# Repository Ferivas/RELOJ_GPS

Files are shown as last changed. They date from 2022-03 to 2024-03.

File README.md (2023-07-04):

# RELOJ_GPS
Reloj GPS basado en matrices 8x8 y drivers A6282.
Se tiene un arreglo de 5 matrices 8x8 manejadas cada una por un driver A6282.
La resolución del display resultante es de 8x40 (8 filas por 40 columnnas). 
Los datos del display se guardan en un arreglo Buffram de 40 bytes

## MICROPYTHON DRIVER
Con Micropython se puede implementar un driver manejando los datos con una instancia del puerto SPI (la línea MOSI no se utiliza).
En este escenario se encontro que para manejar 4 matrices se necesitan 870us para actualizar los datos. Las interrupciones del timer se generan cada 2ms por lo que para un barrido de 8 columnas se tiene una frecuencia de refresco de f=1/(2*8ms)=62.5Hz. Con el osciloscopio se determina que las columas están encendidas 1.4ms, por lo que se tiene un tiempo de (1400-870)/1400=38% del tiempo útil con los datos. En la práctica el brillo es aceptable y no hay efecto de fantasma por la conmutación.
## CONEXION MATRIZ 16X16
Las matrices se arreglan en un formato de 16x16 como se inidica en la figura siguiente:

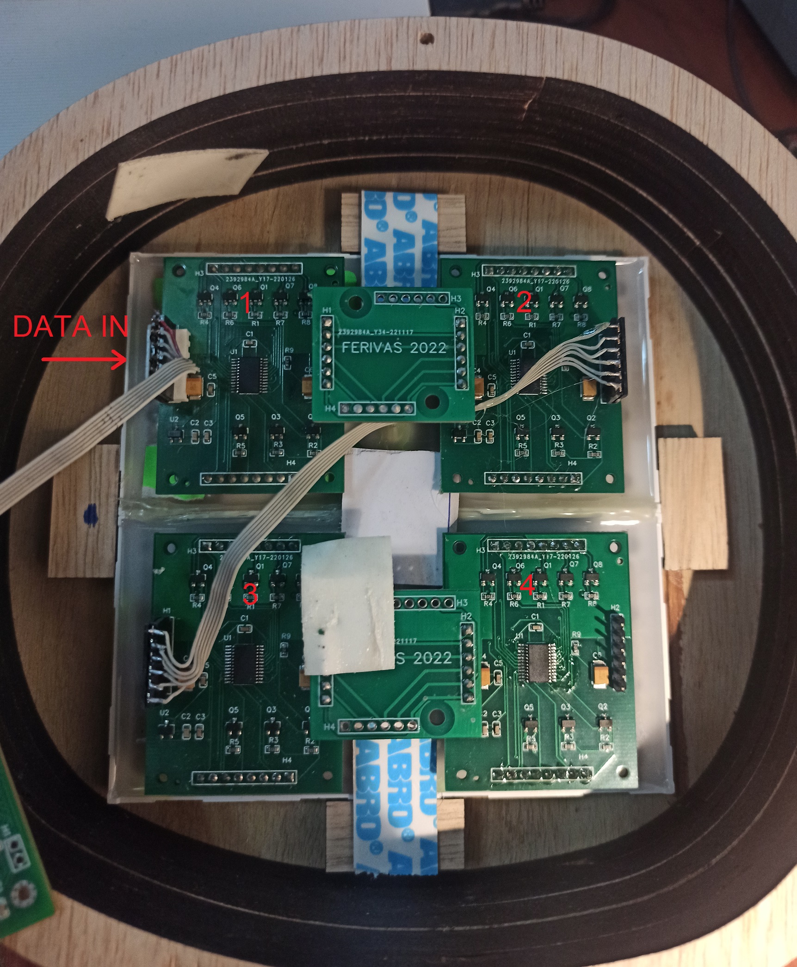
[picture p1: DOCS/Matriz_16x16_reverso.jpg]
Conexion Reverso


Con esta conexión la posición de las columnas para el arreglo bufferram en el programa de Micropython queda como se indica a continuación:

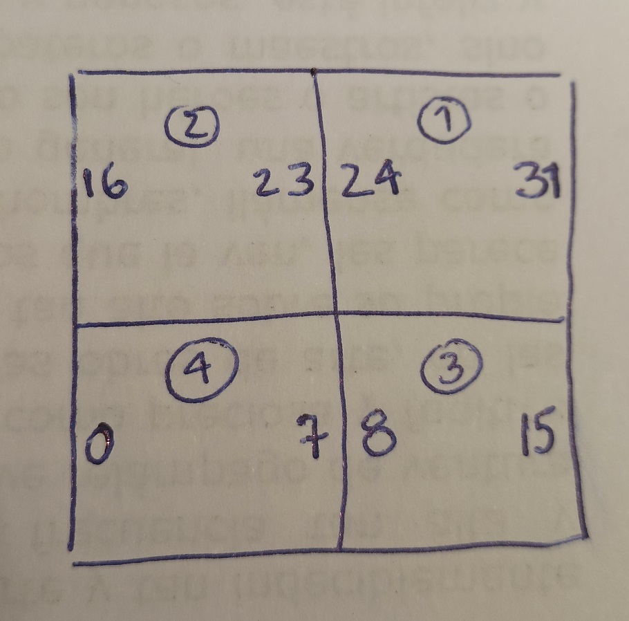
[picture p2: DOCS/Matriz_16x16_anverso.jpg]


En el programa de micropython las posiciones de los dígitos se asignan en una lista 

tblposdig=[10,2,23,16,25,31]

en donde el elemento 0 corresponde a la posición de las unidades de minuto, el elemento 1 a las decenas de minuto, el elemento 2 a las unidades de hora y el elemento 3 a las decenas de hora. 

El reloj por el frente

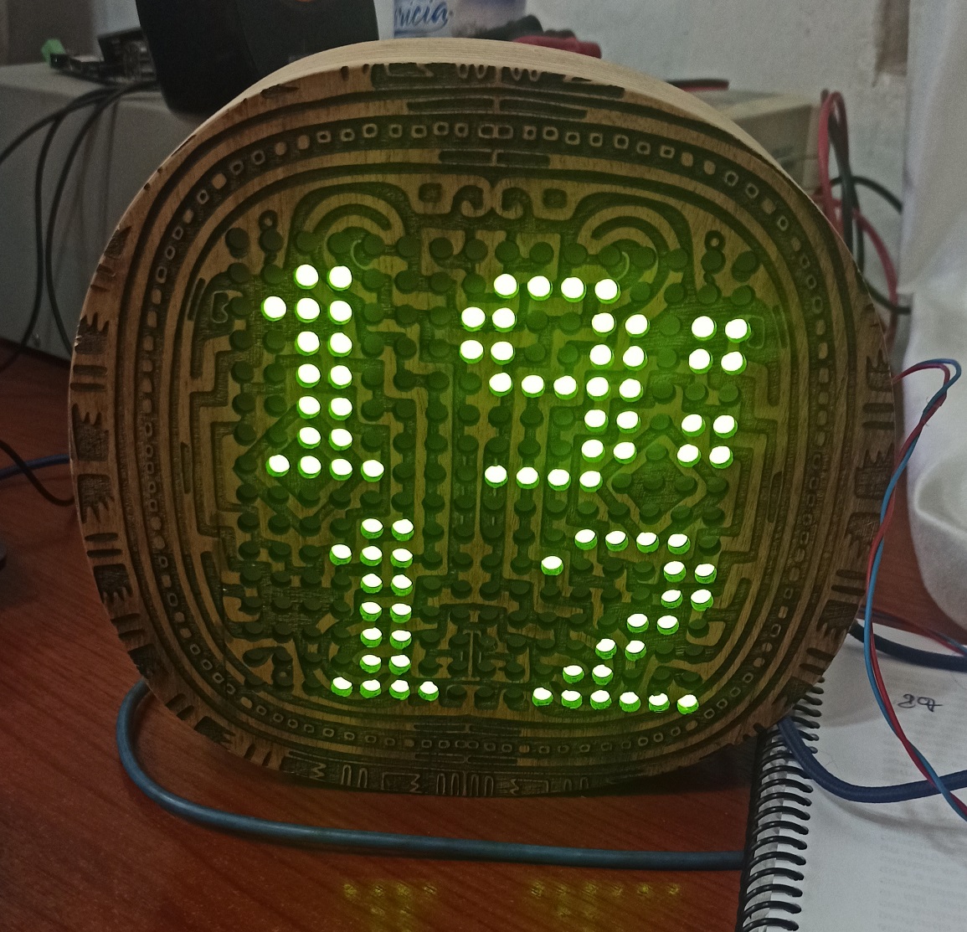
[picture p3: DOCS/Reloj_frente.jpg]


## BUGS RELOJ BASADO EN ESP32 CON TARJETA JLCPCB
### BUGS HARDWARE
Se debe desconectar la línea PWM que une a los dos drivers. Esta línea se debe manejar por separado. Cuando estaban unidos solo se enciende el segundo driver.
El corte esta indicado en la figura siguiente:

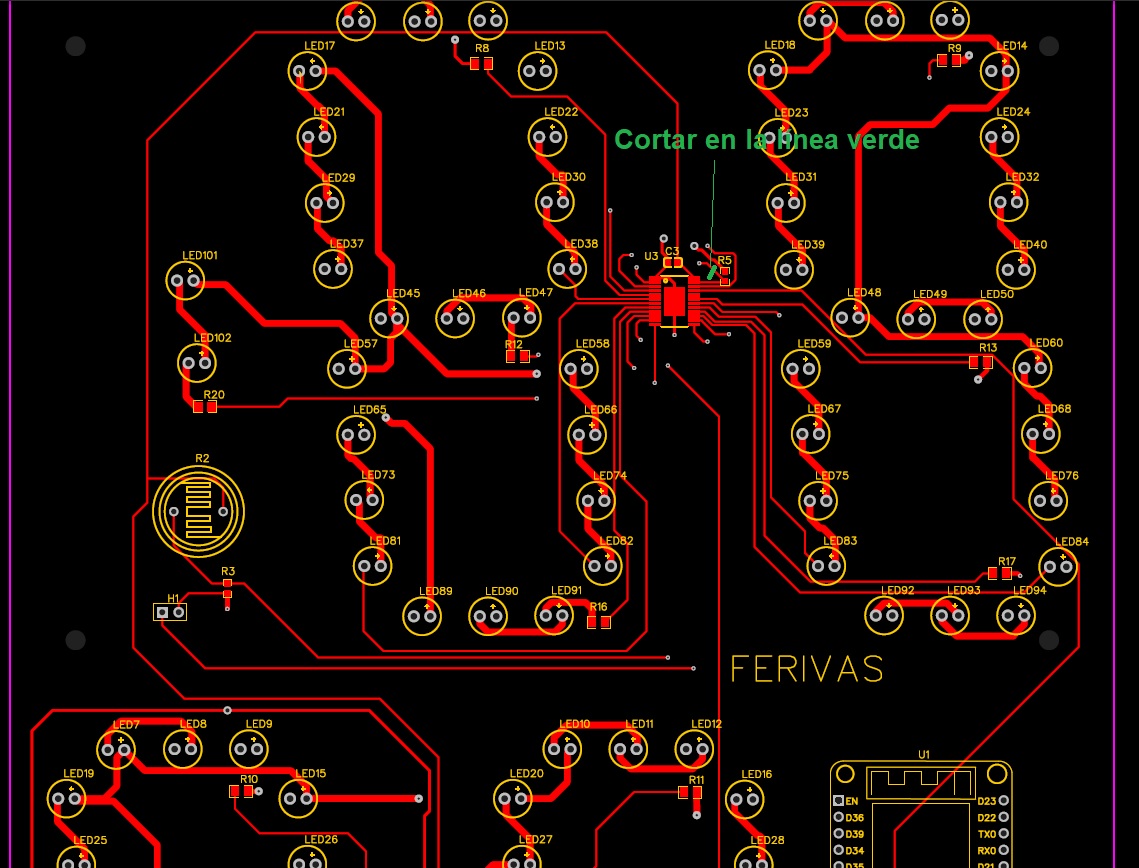
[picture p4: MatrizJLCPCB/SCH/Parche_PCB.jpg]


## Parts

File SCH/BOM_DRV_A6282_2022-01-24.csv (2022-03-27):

ID | Name | Designator | Footprint | Quantity | Manufacturer Part | Manufacturer | Supplier | Supplier Part | Price | JLCPCB Part Class
1 | 100nF | C1,C3,C5 | C0603 | 3 | CC0603KRX7R9BB104 | YAGEO | LCSC | C14663 | 0.003 | Basic Part
2 | 10uF | C2 | C0603 | 1 | CL10A106MA8NRNC | SAMSUNG | LCSC | C96446
3 | 100uF | C4,C6 | CAP-SMD_L3.5-W2.8 | 2 | TAJB107K006RNJ | AVX | LCSC | C16133 | 0.194 | Basic Part
4 | A2541WV-6P | H1,H2 | HDR-TH_6P-P2.54-V-M-1 | 2 | A2541WV-6P | Changjiang Connectors | LCSC | C225481 | 0.119 | Extended Part
5 | AO3401A | Q1,Q2,Q3,Q4,Q5,Q6,Q7,Q8 | SOT-23_L2.9-W1.3-P1.90-LS2.4-BR | 8 | AO3401A | AOS | LCSC | C15127 | 0.149 | Basic Part
6 | 47K | R1,R2,R3,R4,R5,R6,R7,R8 | R0603 | 8 | 0603WAF4702T5E | UniOhm | LCSC | C25819 | 0.001 | Basic Part
7 | 470 | R9 | R0603 | 1 | 0603WAF4700T5E | UniOhm | LCSC | C23179 | 0.001 | Basic Part
8 | XC6206P332MR | U2 | SOT-23-3_L2.9-W1.6-P1.90-LS2.8-BR | 1 | XC6206P332MR | TOREX | LCSC | C5446 | 0.131 | Basic Part

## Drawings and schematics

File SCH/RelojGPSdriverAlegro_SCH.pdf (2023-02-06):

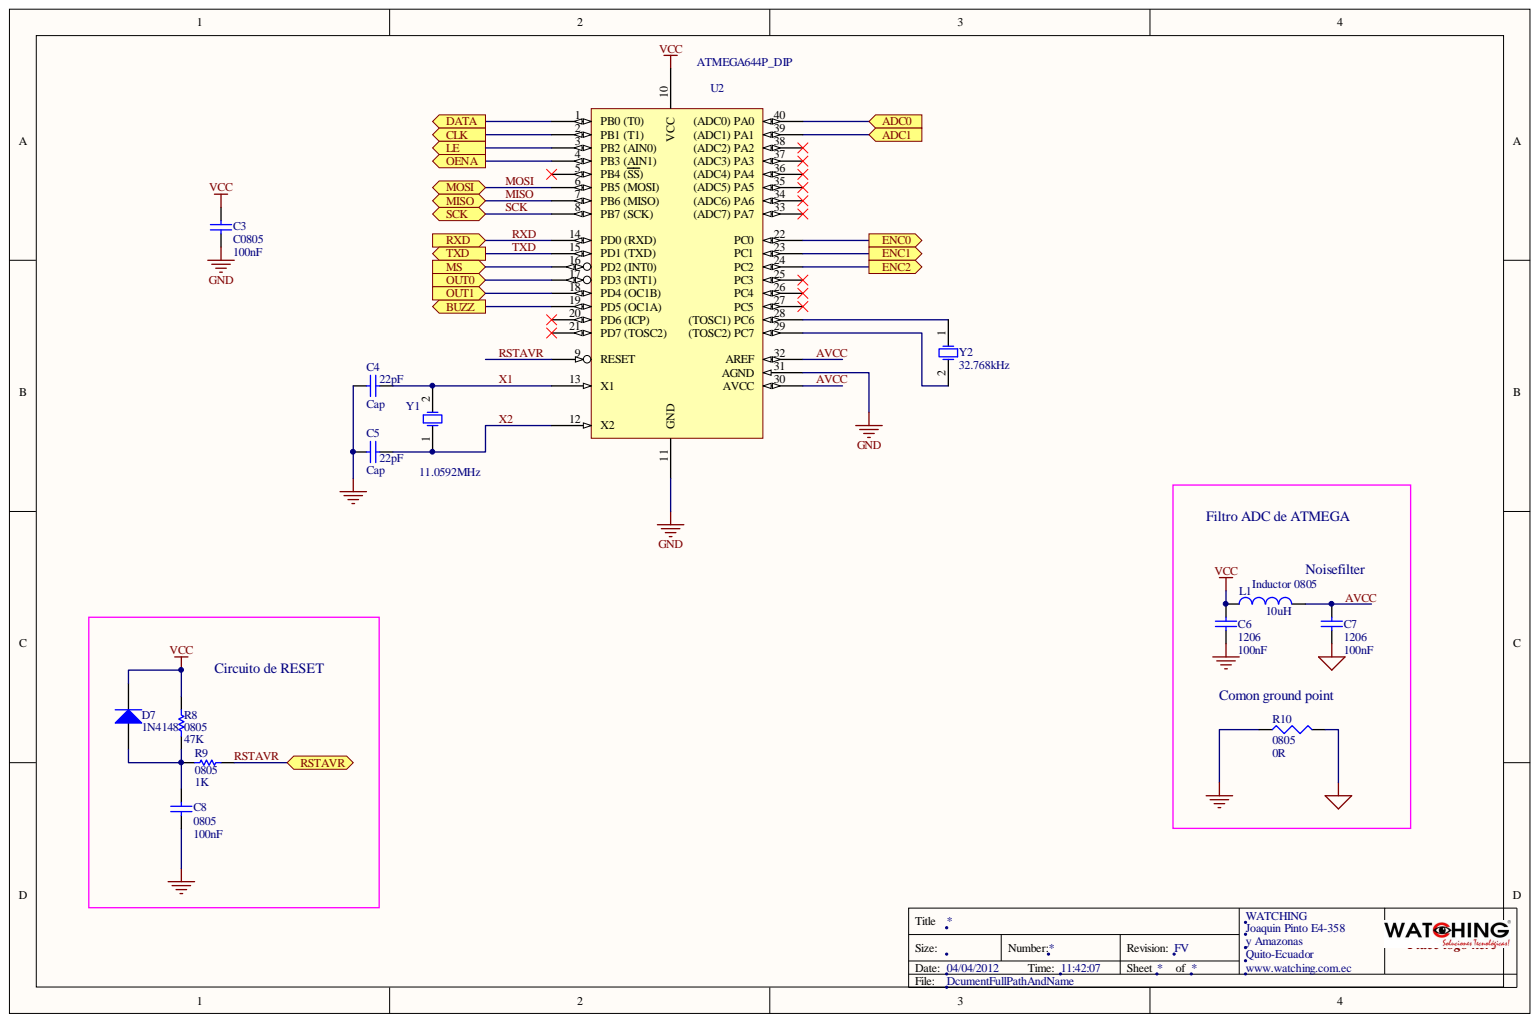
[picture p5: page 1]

Filtro ADC de ATMEGA

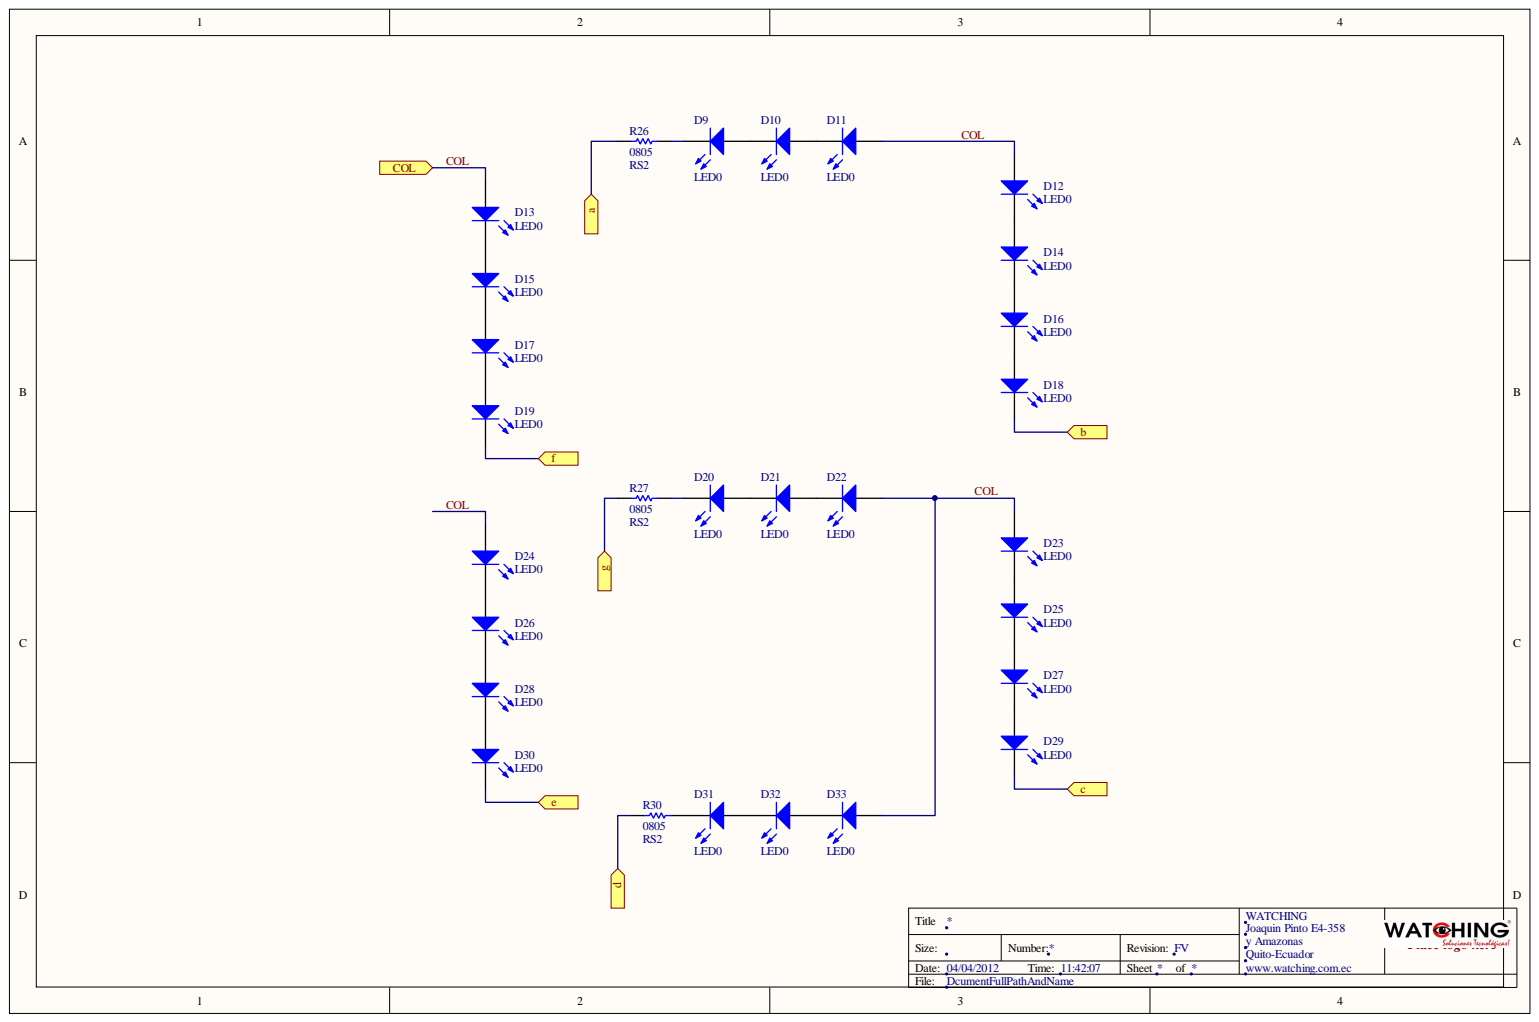
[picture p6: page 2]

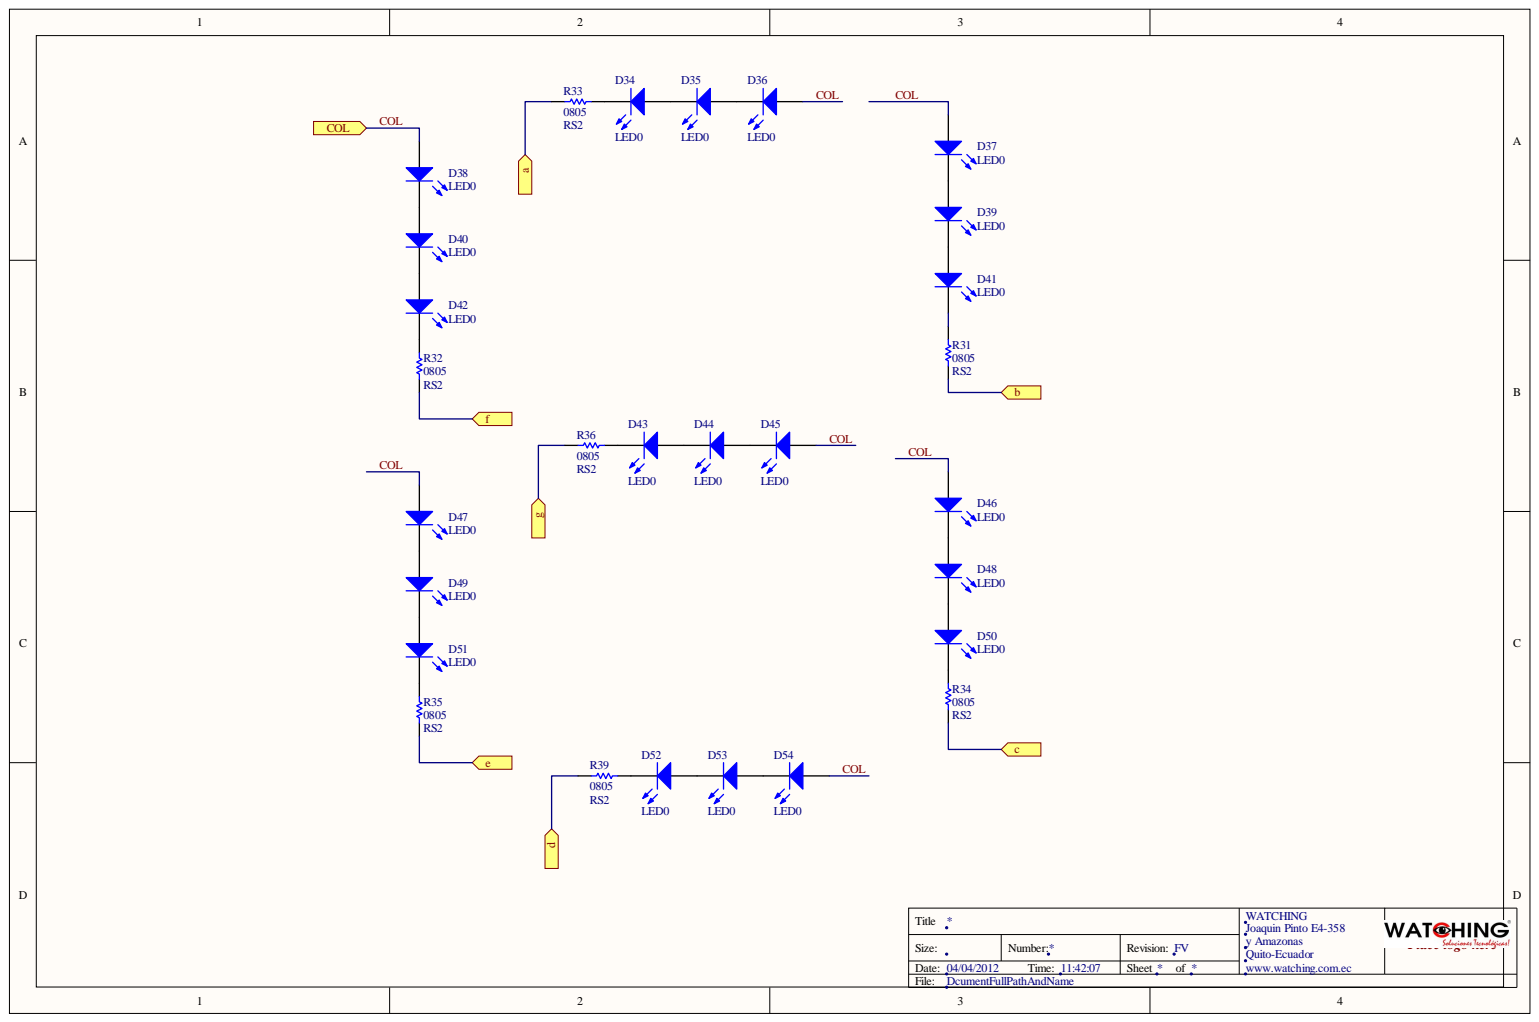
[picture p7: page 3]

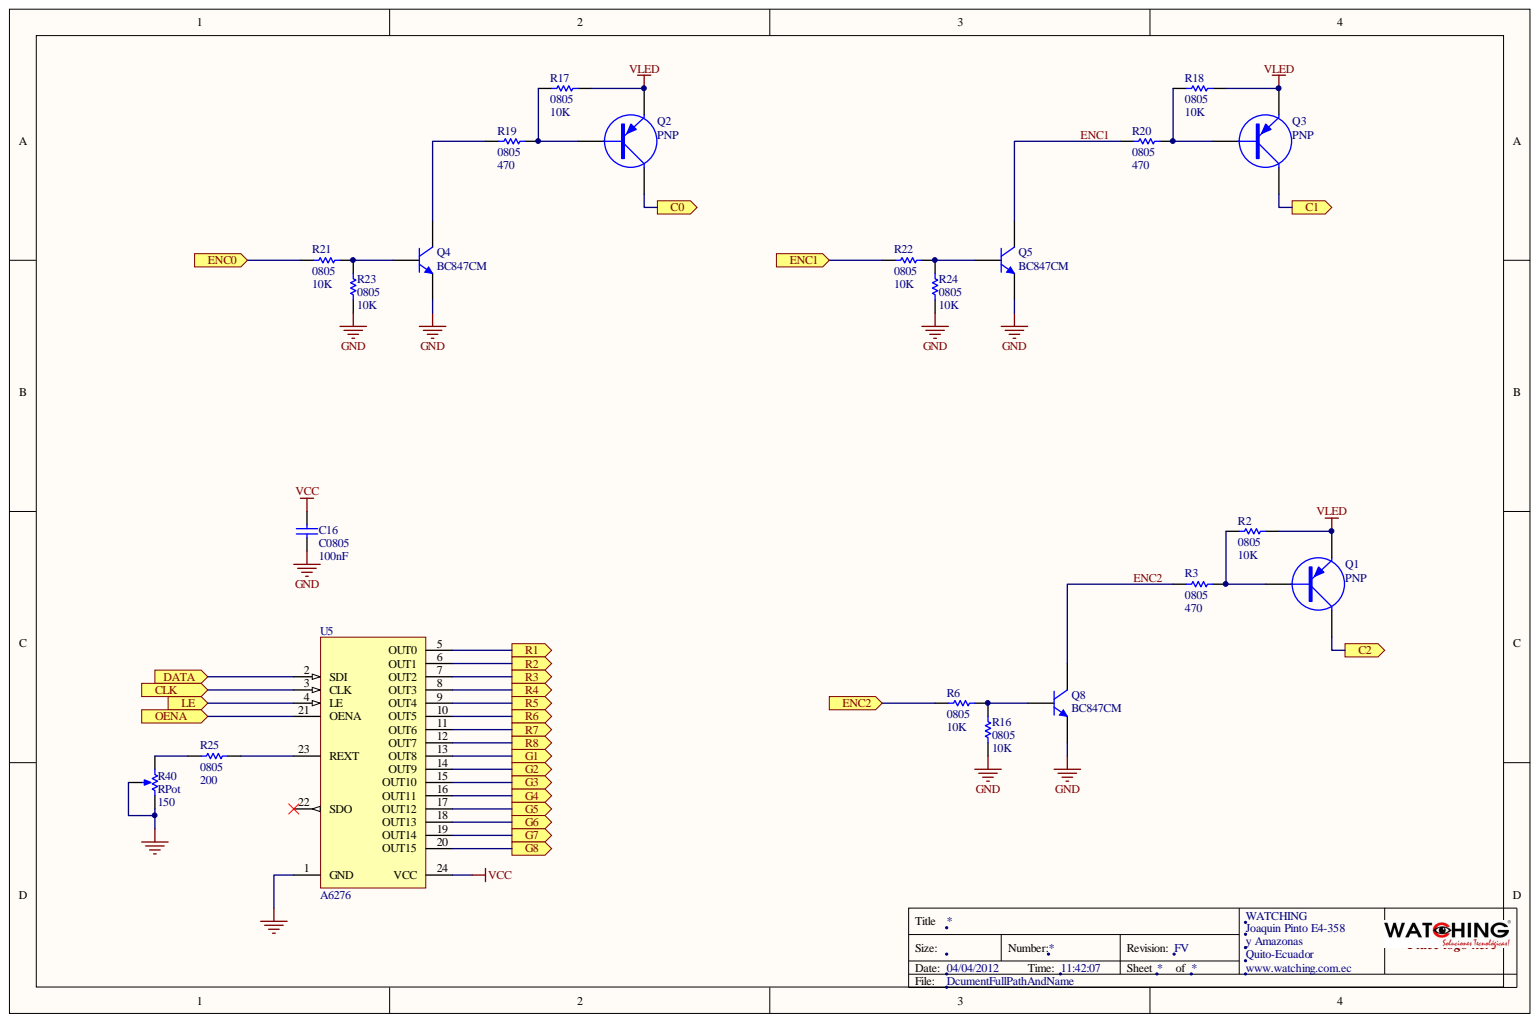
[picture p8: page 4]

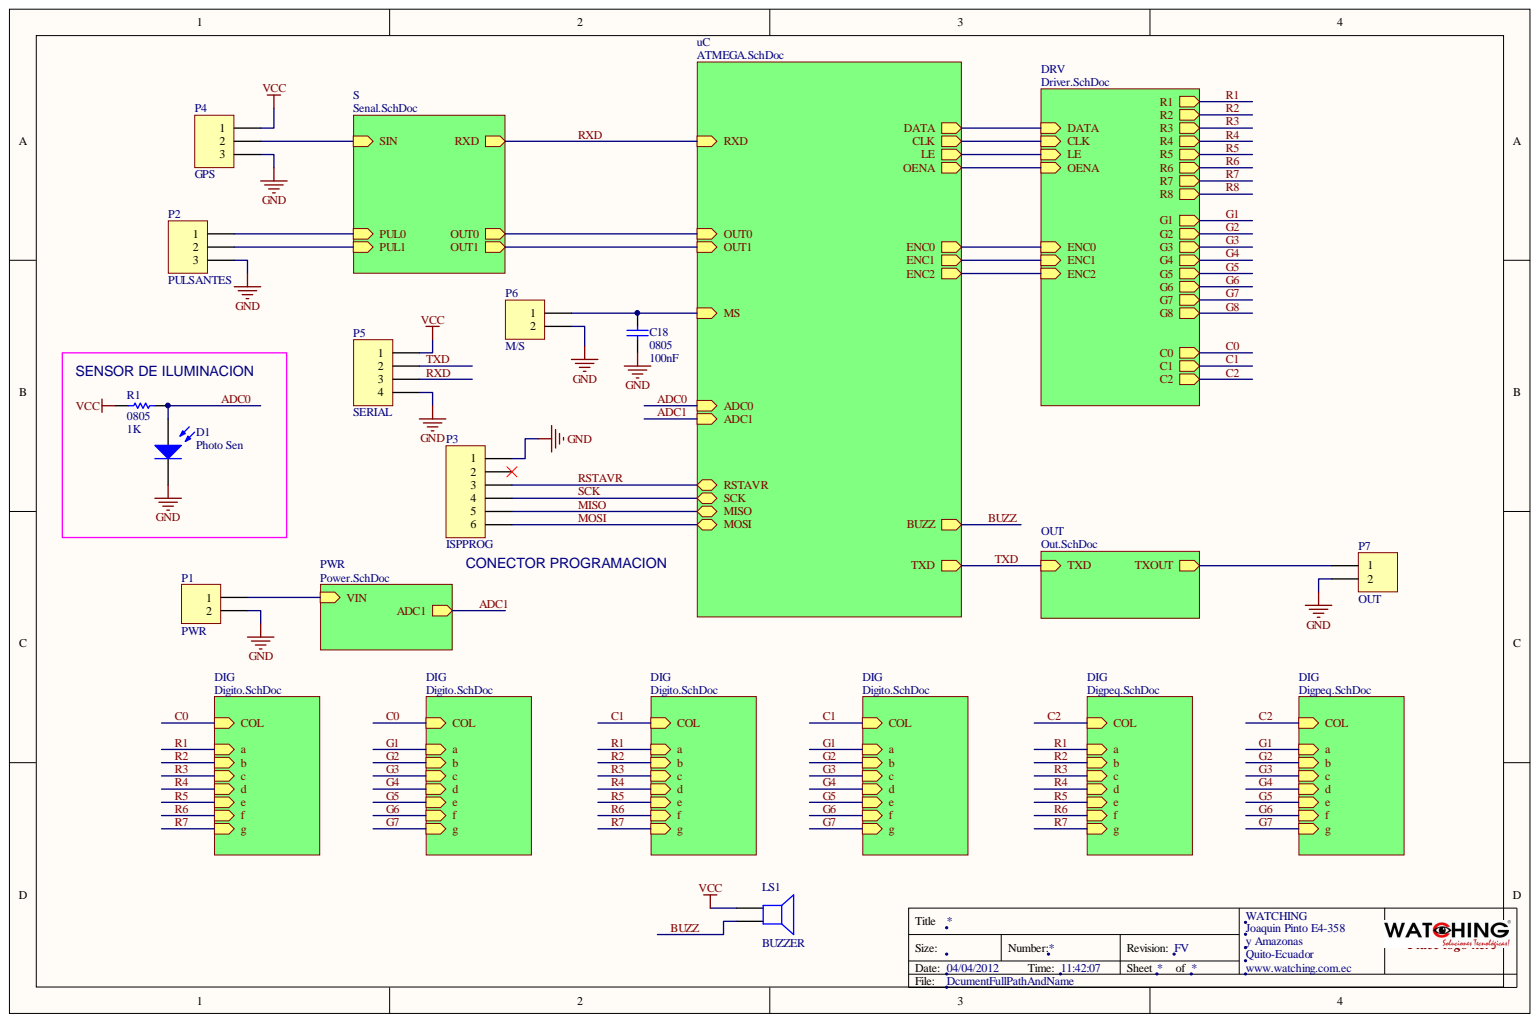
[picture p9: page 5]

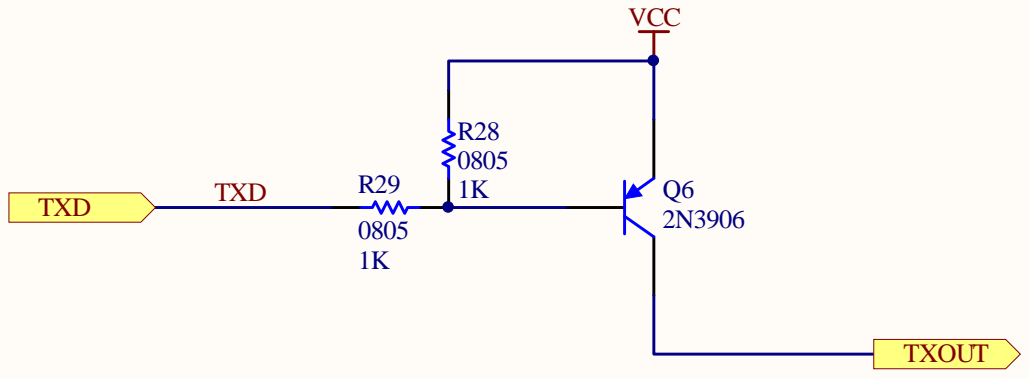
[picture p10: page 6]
Title; Size:; Number:; Revision:; WATCHING; Joaquin Pinto E4-358 y Amazonas Quito-Ecuador; VCC; TXD TXD; TXOUT

Place logo here

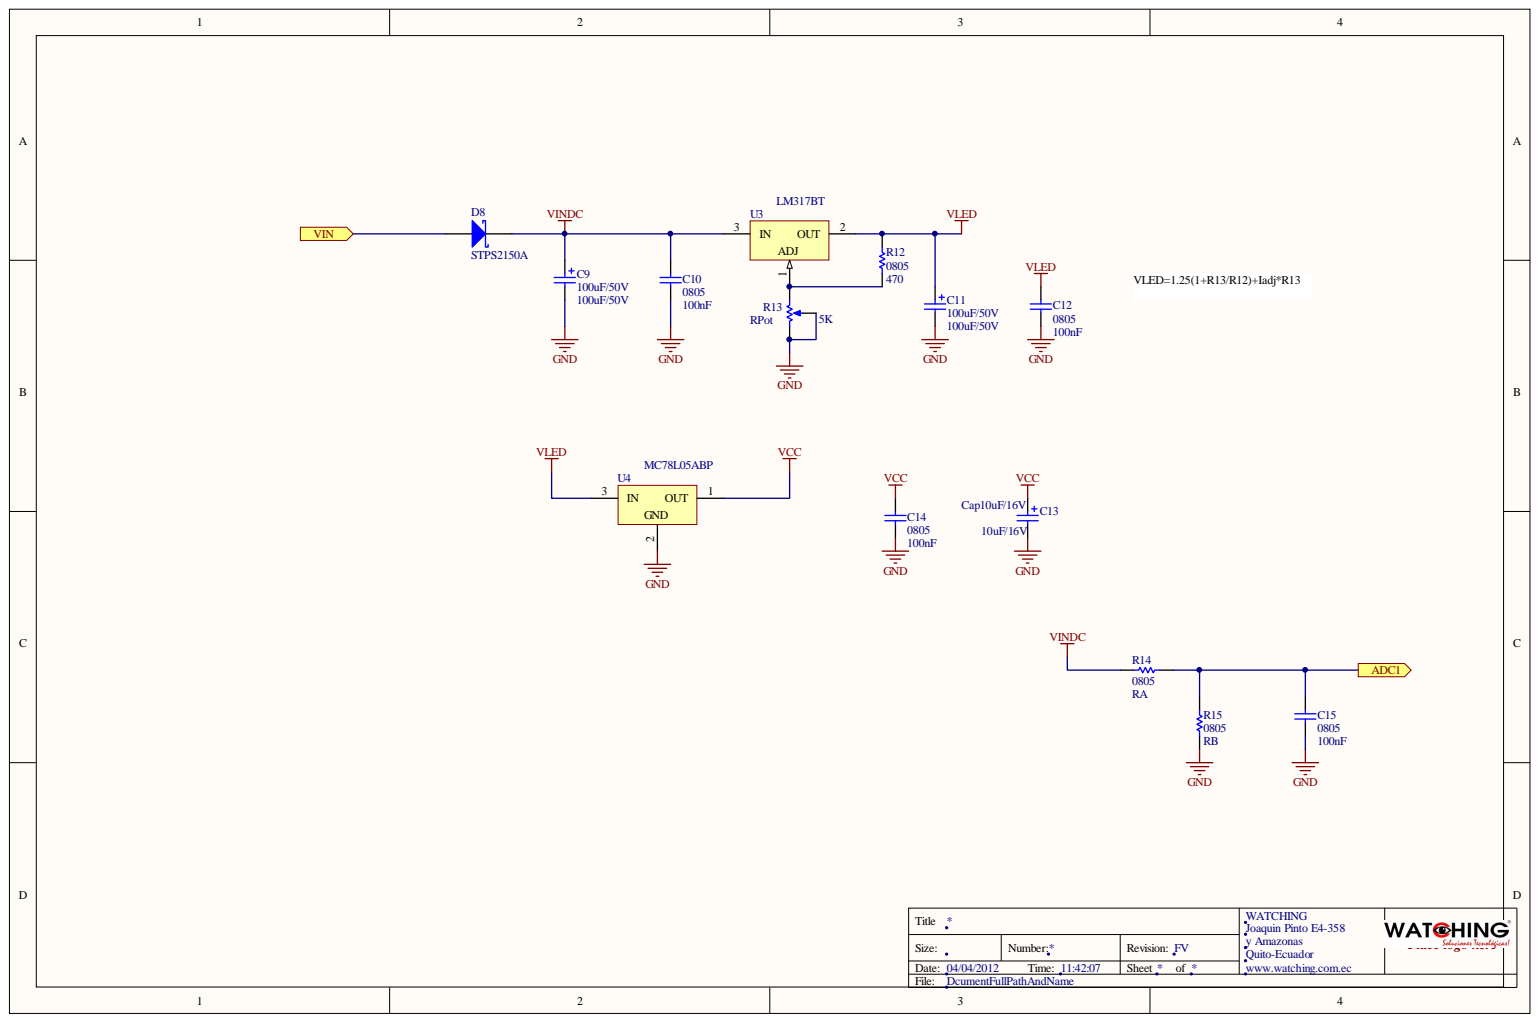
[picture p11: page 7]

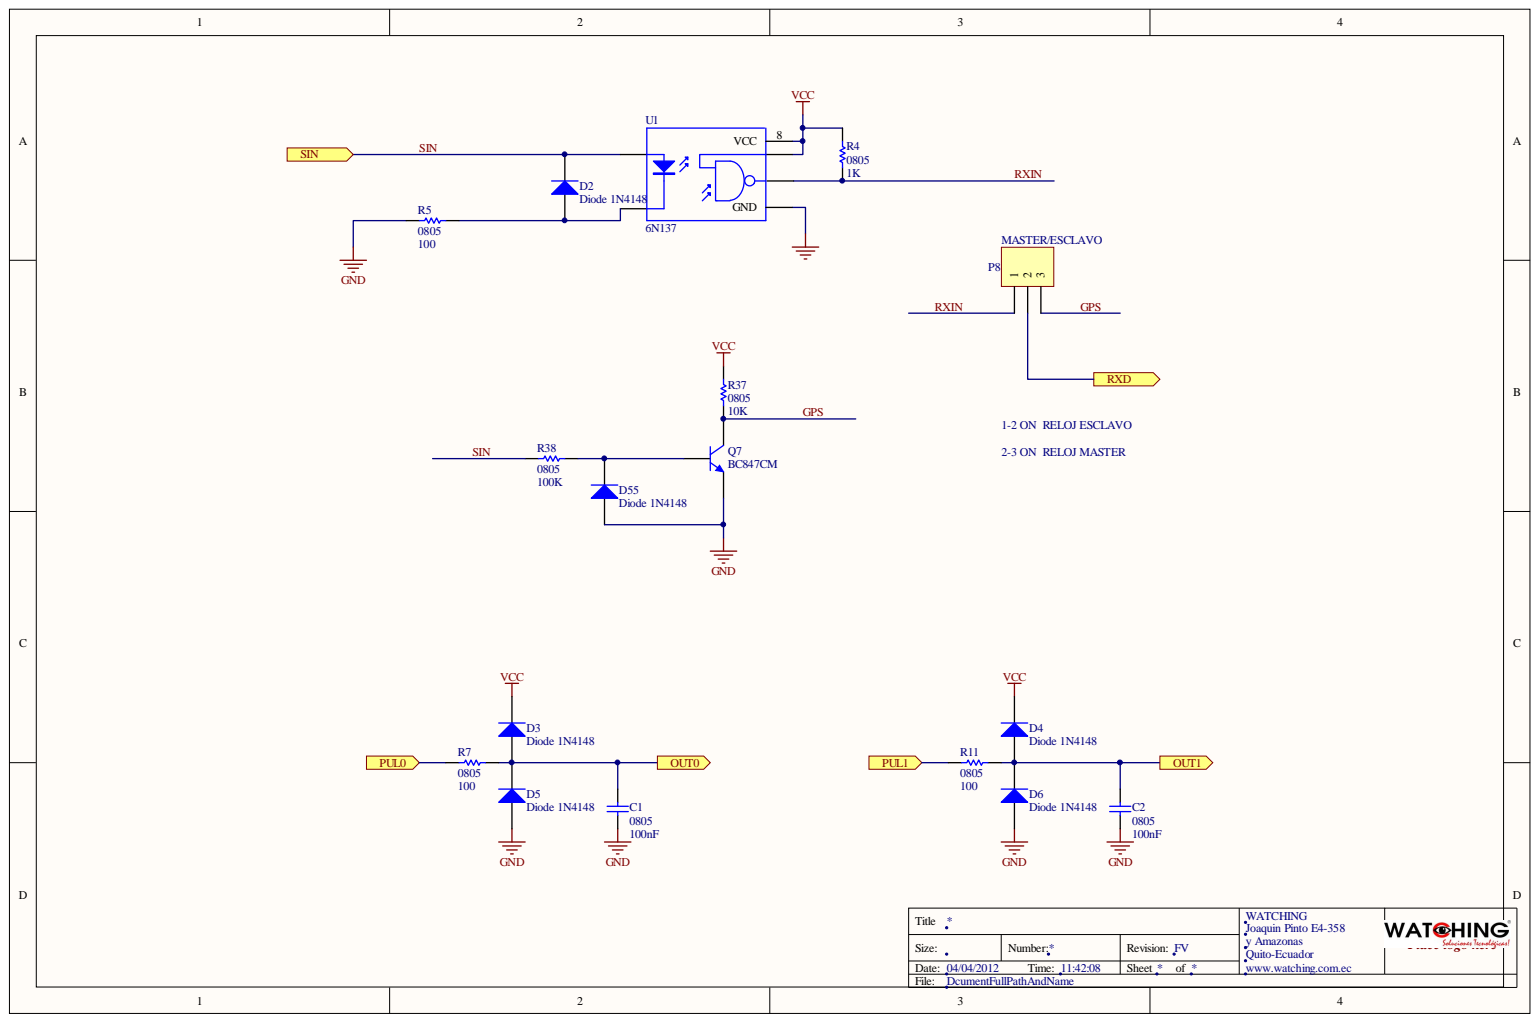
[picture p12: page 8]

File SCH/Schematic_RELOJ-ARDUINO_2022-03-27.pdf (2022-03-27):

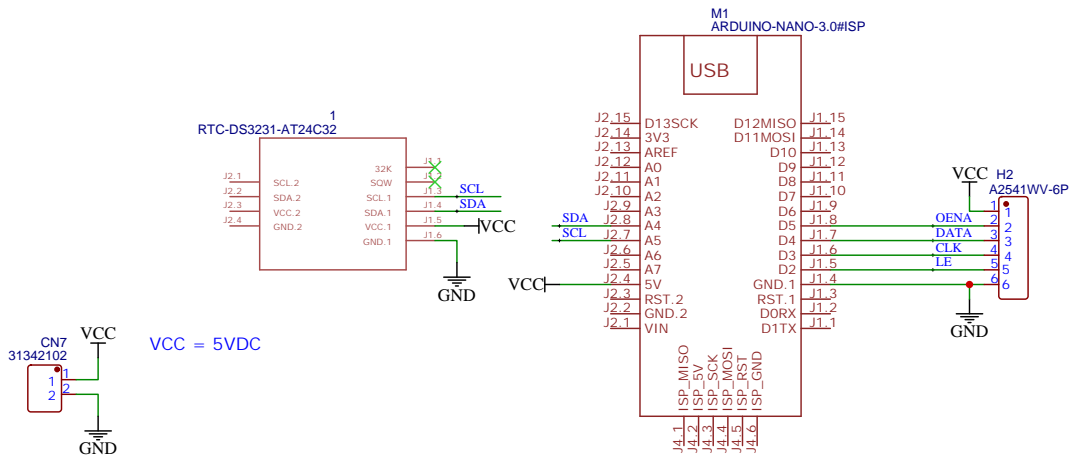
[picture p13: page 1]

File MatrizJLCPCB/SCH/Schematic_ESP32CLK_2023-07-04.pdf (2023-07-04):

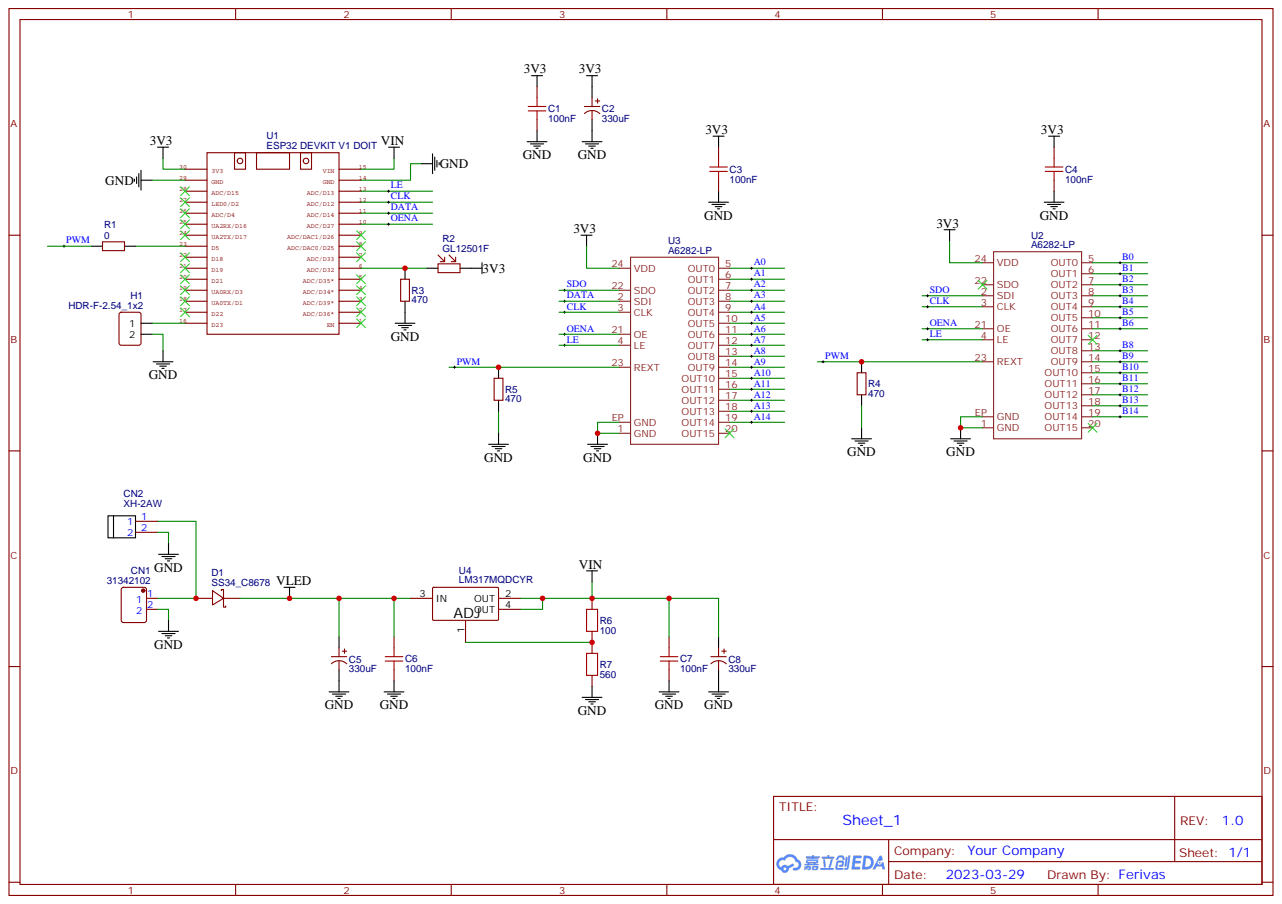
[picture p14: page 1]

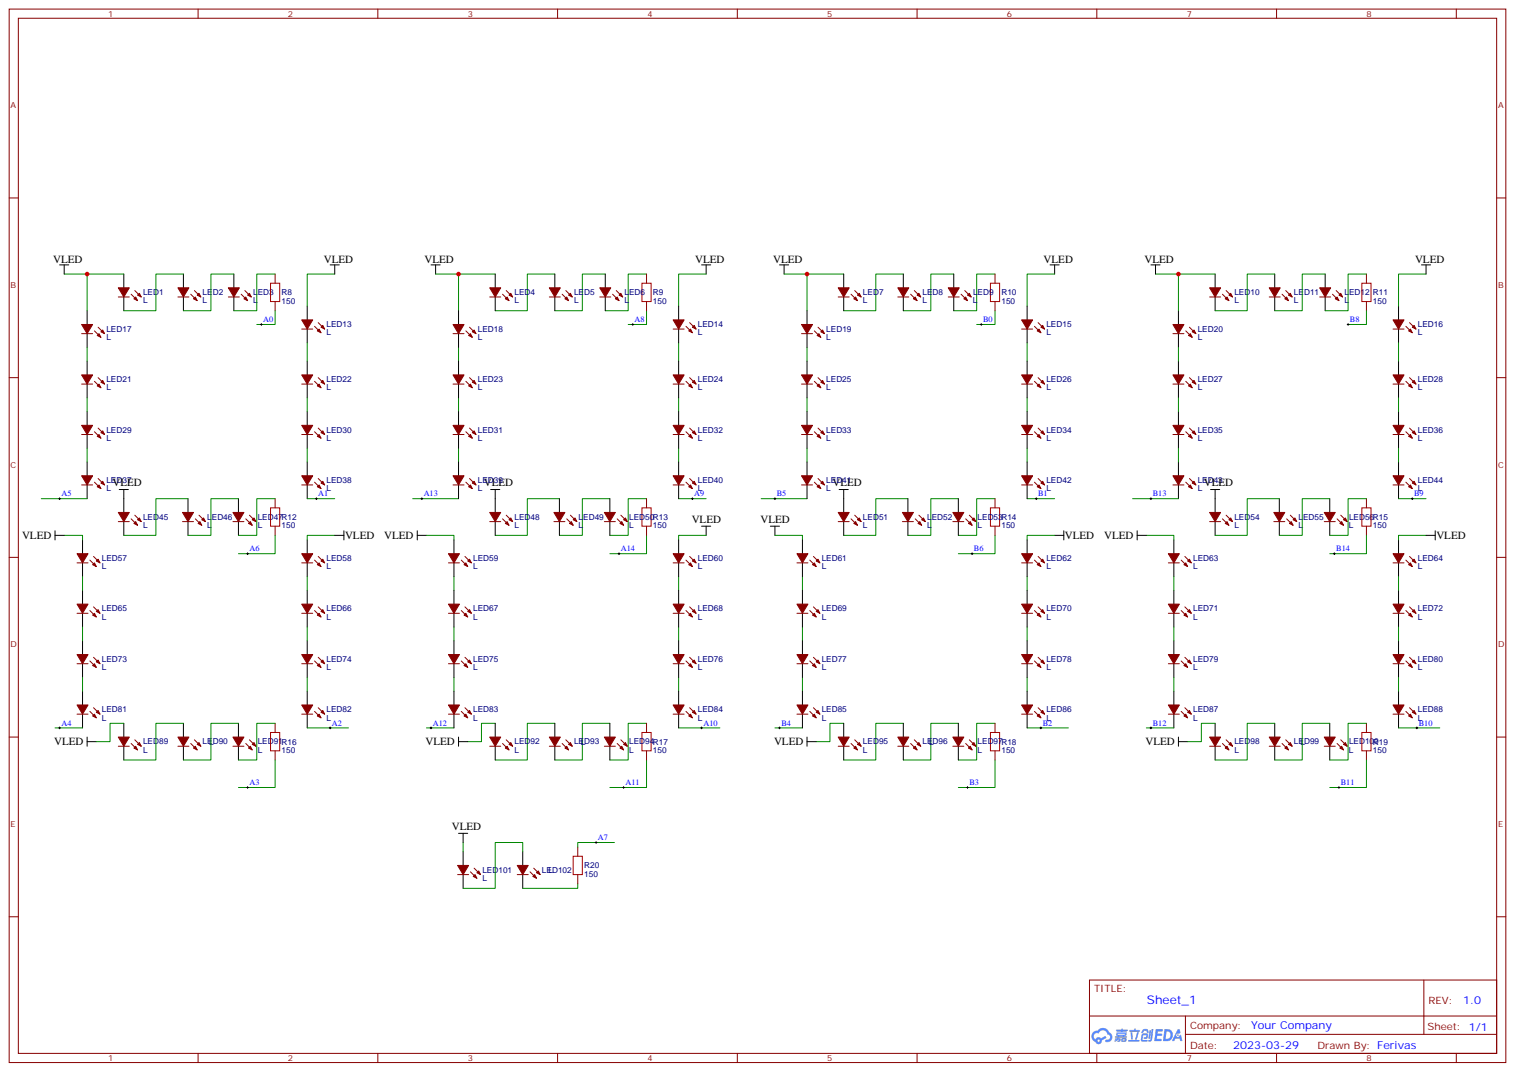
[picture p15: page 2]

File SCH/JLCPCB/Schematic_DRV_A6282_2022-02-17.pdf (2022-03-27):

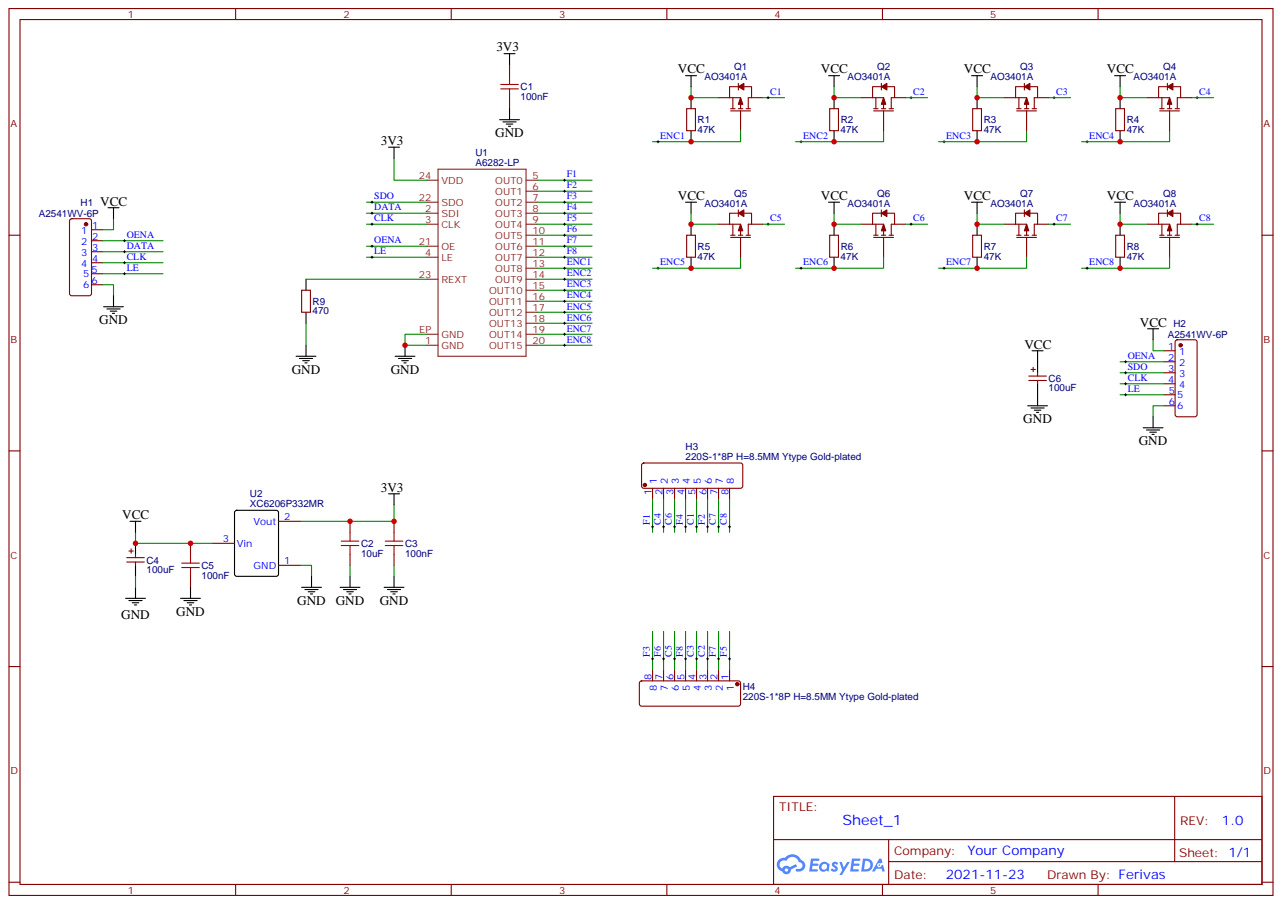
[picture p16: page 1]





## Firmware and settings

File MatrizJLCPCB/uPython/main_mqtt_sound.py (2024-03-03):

import machine
from machine import Pin,SoftSPI,PWM
import time
import ntptime
import wifimgr
import ujson
import urequests as requests
from umqttsimple import MQTTClient
import ubinascii
from dfplayer import DFPlayer


#Declaracion de pines y constantes
ntptime.host = "pool.ntp.org"



VERSION_HW=2
FILECONFIG="configjson.txt"
EQUIPO="reloj"

#Config HW
if VERSION_HW==1:
    LEDPIN=5
    oe = 27
    data = 26;    # pin connected to the serial input of the MAX7219 (DIN)
    clk  = 25;    # pin for the clock of the serial link (CLK)    
    load = 33;    # pin for loading data (CS)
    miso=15 #notused
    PINSELBRK=18
    
if VERSION_HW==2:
    LEDPIN=2
    oe = 27
    data = 14;    # pin connected to the serial input of the MAX7219 (DIN)
    clk = 12;    # pin for loading data (CS)
    load  = 13;    # pin for the clock of the serial link (CLK)
    miso=15 #notused
    PINSELBRK=23

led=Pin(LEDPIN,Pin.OUT)

# Initialize the pins as outputs
oePin = machine.Pin(oe, machine.Pin.OUT)
dataPin = machine.Pin(data, machine.Pin.OUT)
loadPin = machine.Pin(load, machine.Pin.OUT)
clkPin  = machine.Pin(clk, machine.Pin.OUT)
misoPin = machine.Pin(miso, machine.Pin.OUT)
# Set them to level 0
dataPin.off()
loadPin.off()
clkPin.off()
oePin.off()


#DFPLAYER
df=DFPlayer(uart_id=1,tx_pin_id=17,rx_pin_id=16)

#Control brillo PWM
frequency = 5000
oecontrol = PWM(Pin(oe), frequency)
oecontrol.duty(1000)

spi = SoftSPI(sck = clkPin, mosi = dataPin, miso = misoPin)
spi.init(baudrate=100000)

flaginternet=False

ptrcol=0
tled=0
tick=0
def handleInterrupt(timer):
    global tled
    global tick
    global newdig
    tled=tled+1
    tled=tled%1600
    if tled <100:
      led.value(1)
    else:
      led.value(0)
    tick=tick+1
    tick=tick%500
    if tick==0:
        newdig=True    

   

#totalInterruptsCounter = 0
timer = machine.Timer(1)
timer.init(period=2, mode=machine.Timer.PERIODIC, callback=handleInterrupt) #Ints cada 2 ms
tled=0
 

# Write some data in a register of the MAX7219.
buffer = bytearray(2)
def serialWrite(dig1, dig2,dig3,dig4):
    # Set CS to 0 to create a rising edge later
    oePin.on()
    oecontrol.duty(1023)
    buffer[0] = dig1
    buffer[1] = dig2
    spi.write(buffer)
    loadPin.on()
    loadPin.off()
    buffer[0] = dig3
    buffer[1] = dig4
    spi.write(buffer)
    loadPin.on()
    loadPin.off()
    oePin.off()
    oecontrol.duty(brillopwm)

def gendig(valdig):
    datadig=TBLDIG[valdig]
    return datadig

def getntptime():
     print("Hora ini:", time.localtime()) 
     ntptime.settime () # set the RTC's time using ntptime
     tval=ntptime.time()
     tval=tval-18000
     #tfloat=float(tval)
     tclk = time.localtime (tval)
     print(tclk)
     anio=str(tclk[0])
     if tclk[1]>9:
         mes=str(tclk[1])
     else:
         mes="0"+str(tclk[1])
     if tclk[2]>9:
         dia=str(tclk[2])
     else:
         dia="0"+str(tclk[2])
     if tclk[3]>9:
         hora=str(tclk[3])
     else:
         hora="0"+str(tclk[3])
     if tclk[4]>9:
         minu=str(tclk[4])
     else:
         minu="0"+str(tclk[4])
     if tclk[5]>9:
         seg=str(tclk[5])
     else:
         seg="0"+str(tclk[5])
         
     cmdclk=dia+mes+anio[2:]+hora+minu+seg
     print(cmdclk)

TBLDIG=[0B00111111,
0B00110000,
0B01101101,
0B01111001,
0B01110010,
0B01011011,
0B01011111,
0B00110001,
0B01111111,
0B01110011,
0B00000000,
]

print("uPython Matrix JLCPCB con audio")

try:
    print("Buscando conf inicial")
    with open(FILECONFIG,'r') as f:
        varconfig=ujson.load(f)
    print("Var file encontrado")
except:
    print("Inicializando conf inicial")
    varconfig={"equipo":EQUIPO,"tiempontp":3600,"huso":-18000,"chatid":"727498654",
               "botid":"1737167982:AAEfbJSqPZ9RB084GFqNEo_xBPcZRVERbLk","enamsg":True,"brillo":10,"cntrini":0,"filesound":1}
    print("Guardando Var file")
    with open(FILECONFIG,'w') as f:
        ujson.dump(varconfig,f)
        
print(varconfig)
tiempontp=varconfig.get("tiempontp")
print("tiempontp=",tiempontp)
huso=varconfig.get("huso")
print("huso=",huso)
CHATID=varconfig.get("chatid")
BOTID=varconfig.get("botid")
ENAMSG=varconfig.get("enamsg")
brilloval=varconfig.get("brillo")
print("brillo=",brilloval)
cntrini=varconfig.get("cntrini")
print("cntrini=",cntrini)
filesound=varconfig.get("filesound")
print("filesound=",filesound)
brillopwm=round(-brilloval*1023/100+1023)
oecontrol.duty(brillopwm)

print("Telegram>",CHATID,BOTID,ENAMSG)
EQUIPO=varconfig.get("equipo")
print("Equipo>",EQUIPO)

def saveKey(dict, key,value):
    if key in dict.keys():
        #print("Key exist, ", end =" ")
        dict.update({key:value})
        #print("value updated =", value)
    else:
        print("No existe")    

inisound=False
last_message = 0
message_interval = 10
counter = 0
client_id = ubinascii.hexlify(machine.unique_id())
client_idstr=client_id.decode('utf-8')
print(client_id)
cntrini=cntrini+1
print("Cntrini=",cntrini)
try:
    saveKey(varconfig, "cntrini",cntrini)
    with open(FILECONFIG,'w') as f:
        ujson.dump(varconfig,f)
except:
    print("Err save cntrini")

# Defino pin para seleccionar el broker
botonbroker=Pin(PINSELBRK, Pin.IN,Pin.PULL_UP)

#MQTT
testbroker=True
cntrtest1=0
cntrtest2=0
while testbroker:
    if botonbroker.value()==1:
        time.sleep(0.2)
        if botonbroker.value()==1:
            cntrtest1=cntrtest1+1
            if cntrtest1>5:
                mqtt_server = "192.168.2.130"
                #mqtt_server="broker.emqx.io"
                testbroker=False
        else:
            cntrtest1=0
    if botonbroker.value()==0:
        time.sleep(0.2)
        if botonbroker.value()==0:
            cntrtest2=cntrtest2+1
            if cntrtest2>5:
                mqtt_server="broker.emqx.io"
                #mqtt_server = "192.168.2.130"
                testbroker=False

print("Broker>",mqtt_server)

ptrcol=0
print("Gen1")
digito1=gendig(4)
digito2=gendig(3)
digito3=gendig(2)
digito4=gendig(1)
serialWrite(digito1, digito2,digito3,digito4)
tick=0
newdig=False
cntrdig=0
time.sleep(1)
reinicio=0
# digito1=gendig(10)
# digito2=gendig(10)
# digito3=gendig(10)
# digito4=gendig(10)
# serialWrite(digito1, digito2,digito3,digito4)

def sndmsgtelegram(msg,chatid,botid):
    urlbase="https://api.telegram.org"
    url=urlbase+'/bot'+botid+'/sendMessage?chat_id='+chatid+'&disable_web_page_preview=1&parse_mode=Markdown&text='+msg
    try:
        response = requests.get(url)
        if response.status_code == 200:
            results = response.json()
            print(results)
        else:
            print("Error code %s" % response.status_code)
    except:
        print("Error snd Telegram")

def sub_cb(topic, msg):
  global newmqttcmd, mqttcmd, mqtttopic
  print((topic, msg))
  newmqttcmd=True
  mqttcmd=msg
  mqtttopic=topic


def restart_and_reconnect():
  print('Failed to connect to MQTT broker. Reconnecting...')
  time.sleep(5)


try:
    profiles = wifimgr.read_profiles()
    print(profiles)
except:
    print("Sin profiles todavia")

wlan = wifimgr.get_connection()

if wlan is None:
    print("Could not initialize the network connection.")
    while True:
        pass  # you shall not pass :D

flaginternet=True
while True:
    cntrtb=0
    cmderr=0
    cmdtb=False
    print("Var usadas para MQTT")
    tmpstr=EQUIPO+'/'+client_idstr+'/ackresp'
    print(tmpstr)
    topic_ack = bytes(tmpstr, 'utf-8')
    tmpstr=EQUIPO+'/'+client_idstr+'/cmdresp'
    print(tmpstr)
    topic_pub = bytes(tmpstr, 'utf-8')
    tstbroker=True
    while tstbroker:
        try:
          #client = connect_and_subscribe()
          client = MQTTClient(client_id, mqtt_server, port=1883, keepalive=30)
          client.set_callback(sub_cb)
          client.connect()
          tstbroker=False
        except OSError as e:
          print(e)
          restart_and_reconnect()
    newmqttcmd=False
    
    topicname=["cmdrx","config","ackresp","onoff","tiempontp",
               "huso","brillo","inisound"]
    topiclist=[]
    ptr=0
    for i in topicname:
        tmpstr=EQUIPO+'/'+client_idstr+'/'+i
        topictmp=bytes(tmpstr, 'utf-8')
        topiclist.append(topictmp)
        print(tmpstr,",",topiclist[ptr])
        client.subscribe(topiclist[ptr])
        print('Connected to %s MQTT broker, subscribed to %s topic' % (mqtt_server, topiclist[ptr]))
        ptr=ptr+1
    
    print(topiclist)
    
    if reinicio==0:
        atsnd=EQUIPO + " ID "+client_idstr+ " inicia operacion en broker "+mqtt_server+", tiempontp="+str(tiempontp)+", huso="+str(huso)+", brillo="+str(brilloval)+ ", cntrini="+str(cntrini)
    if reinicio==1:
        atsnd=EQUIPO + " ID "+client_idstr+ " REINICIO en broker "+mqtt_server+", tiempontp="+str(tiempontp)+", huso="+str(huso)+", brillo="+str(brilloval)+ ", cntrini="+str(cntrini)
    print(atsnd)
    
    try:
        if ENAMSG:
            sndmsgtelegram(atsnd,CHATID,BOTID)
        else:
            print("No msg")
    except:
        print("ERR snd Telegram")

    try:
        getntptime()
    except:
        print("Err NTP")
        
    dhoraant=99
    uhoraant=99
    dminant=99
    uminant=99
    newd=False
    newntp=False
    cntrt=0
    brokerok=True
    while brokerok:
        try:
            client.check_msg()
            if newmqttcmd:
              newmqttcmd=False
              if mqtttopic == topiclist[4]:
                print('ESPcmdtiempontp>',mqttcmd)
                comando=mqttcmd.decode('utf-8')
                print("Cmd>",comando)
                try:
                    tiempoval=int(comando)
                    tiempontp=tiempoval*3600
                    print("tiempontp=",tiempontp, "seg")
                    saveKey(varconfig, "tiempontp",tiempontp)
                    with open(FILECONFIG,'w') as f:
                        ujson.dump(varconfig,f)
                    
                except:
                    print("err tiempontp")

              if mqtttopic == topiclist[5]:
                print('ESPcmdhuso>',mqttcmd)
                comando=mqttcmd.decode('utf-8')
                print("Cmd>",comando)
                try:
                    husof=float(comando)*3600
                    huso=int(husof)
                    print("Huso=",huso)
                    saveKey(varconfig, "huso",huso)
                    with open(FILECONFIG,'w') as f:
                        ujson.dump(varconfig,f)

                except:
                    print("err huso")
                
                
              if mqtttopic == topiclist[6]:
                print('ESPcmdbrillo>',mqttcmd)
                brillostr=mqttcmd.decode('utf-8')
                print("Cmd>",brillostr)
                brilloval=int(brillostr)
                brillopwm=round(-brilloval*1023/100+1023)
                print(brillopwm)
                oecontrol.duty(brillopwm)
                try:
                    print("Save brillo")
                    saveKey(varconfig, "brillo",brilloval)
                    with open(FILECONFIG,'w') as f:
                        ujson.dump(varconfig,f)

                except:
                    print("err savekey")
                    
              if mqtttopic == topiclist[7]:  #inisound
                print('ESPcmdsound>',mqttcmd)
                comando=mqttcmd.decode('utf-8')
                print("Cmd>",comando)
                try:
                    if comando=="0":
                        inisound=False
                    if comando=="1":
                        inisound=True

                except:
                    print("err huso")                    
                

            if inisound:
                inisound=False
                try:
                    df.volume(25)
                    time.sleep(0.2)
                    #play file ./01/001.mp3
                    print("Play file")
                    df.play(2,3)
                except:
                    print("Err sound")

            if newdig:
             newdig=False
             #print(time.time())
             if tiempontp!=0:
                 tntp=time.time()%tiempontp
                 if tntp==0:
                     print("nuevo NTP")
                     newntp=True
             cntrdig=cntrdig+1
             tc=cntrdig%2
             tclk=time.time()
             tclk=tclk+huso
             #tfloat=float(tclk)
             tval = time.localtime (tclk)     
             if tval[3]<10:
                 dhora=0
                 uhora=tval[3]
             else:
                 horastr=str(tval[3])
                 dhora=int(horastr[0])
                 uhora=int(horastr[1])
                 
             if tval[4]<10:
                 dmin=0
                 umin=tval[4]
             else:
                 horastr=str(tval[4])
                 dmin=int(horastr[0])
                 umin=int(horastr[1])         
        
             if dhora!=dhoraant:
                 dhoraant=dhora
                 newd=True
             if uhora!=uhoraant:
                 uhoraant=uhora
                 #newntp=True         
                 newd=True
        
             if dmin!=dminant:
                 dminant=dmin
                 newd=True
             if umin!=uminant:
                 uminant=umin
                 newd=True
                 #newntp=True         
        
             newd=True
             if newd:
                 newd=False
                 #print(dhora,uhora,dmin,umin)
                 digito1=gendig(dhora)
                 digito2=gendig(uhora)
                 if tc==0:
                     digito2=digito2 & 0b01111111
                 else:
                     digito2=digito2 | 0b10000000
                 digito3=gendig(dmin)
                 digito4=gendig(umin)
                 serialWrite(digito3, digito4,digito1,digito2)
              
             if newntp:
                newntp=False
                gendig(10)
                gendig(10)
                gendig(10)
                gendig(10)
                serialWrite(digito3, digito4,digito1,digito2)
                try:
                    getntptime()
                except:
                    print("Err NTP")
                newd=True

             if (time.time() - last_message) > message_interval:
                msg = client_idstr+","+str(counter)
                try:
                    client.publish(topic_pub, msg)
                except:
                    print("Err pub")
                last_message = time.time()
                counter += 1                    

        except OSError as e:
            print("Uy>",e)
            restart_and_reconnect()
            reinicio=1
            brokerok=False                
                
        

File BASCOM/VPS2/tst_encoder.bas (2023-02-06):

$regfile = "m168def.dat"
$crystal = 7372800
$baud = 9600


$hwstack = 116
$swstack = 116
$framesize = 116



Print "Encoder test"

Dim B As Byte

'we have dimmed a byte because we need to maintain the state of the encoder


Swenc Alias Pinb.5
Config Swenc = Input
Set Portb.5

Set Portb.3
Set Portb.4

'Portb = &B11                                               ' activate pull up registers

   Print Version(1)
   Print Version(2)
   Print  Version(3)


Do

  B = Encoder(pinb.3 , Pinb.4 , Links , Rechts , 1)

  '                                               ^--- 1 means wait for change which blocks programflow

  '                               ^--------^---------- labels which are called

  '              ^-------^---------------------------- port PINs

  Print B

Waitms 10

Loop

End



'so while you can choose PINB0 and PINB7,they must be both member of PINB

'this works on all PIN registers



Links:

Print "left rotation"

Return



Rechts:

Print "right rotation"

Return

End

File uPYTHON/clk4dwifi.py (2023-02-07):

import machine
from machine import Pin,SPI
import time
import ntptime
import wifimgr


#Declaracion de pines y constantes
ntptime.host = "pool.ntp.org"

LEDPIN=5
led=Pin(LEDPIN,Pin.OUT)

LEDBUG=18
ledbug=Pin(LEDBUG,Pin.OUT)

NUMMATRIZ=4
LONGBUF=NUMMATRIZ*8
datocero=0b00000000
buffram=[]
for i in range(LONGBUF+1):
    buffram.append(datocero)

oe = 27
oePin = machine.Pin(oe, machine.Pin.OUT)
#Config HW
data = 26;    # pin connected to the serial input of the MAX7219 (DIN)
load = 33;    # pin for loading data (CS)
clk  = 25;    # pin for the clock of the serial link (CLK)
miso=15 #notused
# Initialize the pins as outputs
dataPin = machine.Pin(data, machine.Pin.OUT)
loadPin = machine.Pin(load, machine.Pin.OUT)
clkPin  = machine.Pin(clk, machine.Pin.OUT)
misoPin = machine.Pin(miso, machine.Pin.OUT)
# Set them to level 0
dataPin.off()
loadPin.off()
clkPin.off()

spi = machine.SPI(-1, sck = clkPin, mosi = dataPin, miso = misoPin)

columnas=[0b00000001,0b00000010,0b00000100,0b00001000,0b00010000,0b00100000,0b01000000,0b10000000]
#tblposdig=[1,9,19,27,25,31]
tblposdig=[1,10,19,27,25,31]
coldata = bytearray(columnas)
datocolumna=bytearray(1)
ptrcol=0
def handleInterrupt(timer):
    global interruptCounter
    global datocolumna
    global ptrcol
    global datodat
    interruptCounter = False
    oePin.on()
    datocolumna=coldata[ptrcol]
    datodat=buffram[ptrcol]
    ptrcol=ptrcol+1
    ptrcol=ptrcol%8
    serialWrite(datocolumna,datocero)
    serialWrite(datocolumna,datocero)
    serialWrite(datocolumna,datocero)
    serialWrite(datocolumna,datocero)
    serialWrite(datocolumna,datodat)
    serialWrite(datocolumna,buffram[ptrcol+8])
    serialWrite(datocolumna,buffram[ptrcol+16])
    serialWrite(datocolumna,buffram[ptrcol+24])        
    oePin.off() 
    interruptCounter=True

interruptCounter = False
#totalInterruptsCounter = 0
timer = machine.Timer(1)
timer.init(period=2, mode=machine.Timer.PERIODIC, callback=handleInterrupt) #Ints cada 2 ms
tled=0
 
# Send a byte bit by bit to the MAX7219, most significant bit first
def serialShiftByte(data):
    # Set the clock to 0 in order to be able to make a rising edge later
    clkPin.off()
    # Shift the 8 bits of data
    spi.write(data)
# Write some data in a register of the MAX7219.
buffer = bytearray(2)
def serialWrite(address, data):
    # Set CS to 0 to create a rising edge later
    buffer[0] = address
    buffer[1] = data    
    loadPin.off()
    # Send the address of the register first
    spi.write(buffer)
    # then the data
    # make a rising edge on CS to load the transmitted data into the register
    loadPin.on()
    loadPin.off()
# Send a byte bit by bit to the MAX7219, most significant bit first

def gendig(valdig,posdig):
    ptrdig=valdig*6
    ptrpos=tblposdig[posdig]
    #print("Ptrpos>",ptrpos)
    for i in range(6):
        ptr=ptrdig+i
        #print("ptr>",ptr)
        datadig=TBLDIG[ptr]
        ptr2=ptrpos+i-1
        buffram[ptr2]=datadig
        #print("ptr2>",ptr2)
    

def getntptime():
     print("Hora inicial:", time.localtime()) 
     ntptime.settime () # set the RTC's time using ntptime
     tval=ntptime.time()
     tval=tval-18000
     #tfloat=float(tval)
     tclk = time.localtime (tval)
     print(tclk)
     anio=str(tclk[0])
     if tclk[1]>9:
         mes=str(tclk[1])
     else:
         mes="0"+str(tclk[1])
     if tclk[2]>9:
         dia=str(tclk[2])
     else:
         dia="0"+str(tclk[2])
     if tclk[3]>9:
         hora=str(tclk[3])
     else:
         hora="0"+str(tclk[3])
     if tclk[4]>9:
         minu=str(tclk[4])
     else:
         minu="0"+str(tclk[4])
     if tclk[5]>9:
         seg=str(tclk[5])
     else:
         seg="0"+str(tclk[5])
         
     cmdclk=dia+mes+anio[2:]+hora+minu+seg
     print(cmdclk)

TBLDIG=[0B01111110,
0B11111111,
0B10000001,
0B10000001,
0B11111111,
0B01111110,
0B00000000,
0B00000001,
0B11111111,
0B11111111,
0B01000001,
0B00100000,
0B01100001,
0B11110001,
0B10010001,
0B10010001,
0B10011111,
0B10001111,
0B01101110,
0B11111111,
0B10010001,
0B10010001,
0B10010001,
0B10000001,
0B11111111,
0B11111111,
0B00001000,
0B00001000,
0B11111000,
0B11110000,
0B10001110,
0B10011111,
0B10010001,
0B10010001,
0B11110001,
0B11110001,
0B00001110,
0B10011111,
0B10010001,
0B10010001,
0B11111111,
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
]

print("uPython Matrix")
ptrcol=0
datocero=0b00000000
datodat=0b001000100
print("Gen1")
gendig(4,0)
gendig(3,1)
gendig(2,2)
gendig(1,3)
tick=0
newdig=False
cntrdig=0

try:
    profiles = wifimgr.read_profiles()
    print(profiles)
except:
    print("Sin profiles todavia")

wlan = wifimgr.get_connection()

if wlan is None:
    print("Could not initialize the network connection.")
    while True:
        pass  # you shall not pass :D


try:
    getntptime()
except:
    print("Err NTP")
    
dhoraant=99
uhoraant=99
dminant=99
uminant=99
newd=False
newntp=False
while True:
  if interruptCounter:
    interruptCounter = False
    tled=tled+1
    tled=tled%1600
    if tled <100:
      led.value(1)
    else:
      led.value(0)
    tick=tick+1
    tick=tick%500
    if tick==0:
        newdig=True
  if newdig:
     newdig=False
     #print(time.localtime())
     cntrdig=cntrdig+1
     tc=cntrdig%2
     if tc==0:
         buffram[17]=0b00000000
     else:
         buffram[17]=0b00110110
     tclk=time.time()
     tclk=tclk-18000
     #tfloat=float(tclk)
     tval = time.localtime (tclk)     
     if tval[3]<10:
         dhora=0
         uhora=tval[3]
     else:
         horastr=str(tval[3])
         dhora=int(horastr[0])
         uhora=int(horastr[1])
         
     if tval[4]<10:
         dmin=0
         umin=tval[4]
     else:
         horastr=str(tval[4])
         dmin=int(horastr[0])
         umin=int(horastr[1])         

     if dhora!=dhoraant:
         dhoraant=dhora
         newd=True
     if uhora!=uhoraant:
         uhoraant=uhora
         newntp=True         
         newd=True

     if dmin!=dminant:
         dminant=dmin
         newd=True
     if umin!=uminant:
         uminant=umin
         newd=True

     if newd:
         newd=False
         gendig(dhora,3)
         gendig(uhora,2)
         gendig(dmin,1)
         gendig(umin,0)
      
     if newntp:
        newntp=False
        try:
            getntptime()
        except:
            print("Err NTP")         
      
      
print("FIN tst Timer")      

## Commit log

2020-02-08 Tx datos a matriz con tablas de lookup
2020-02-08 Vrificacion de bugs en disposicion de filas y columnas
2020-02-11 Depurado disposicion de filas y columnas
2020-02-20 Generacion de reloj y eliminacion de fantasmas
2020-08-04 Se utiliza frecuencia de barrido a 480Hz
    No se pudo utilizar frecuencia de 1000Hz para el barrido.
    Se multiplexan las 8 columnas de las matrices de leds, por lo que la frecuencia de barrido efectivo es 480/8=60Hz
2020-08-06 Añadido contador de inicios para verificar reinicios
2022-03-27 Actualiza Archivos
    [BOM_DRV_A6282_2022-01-24.csv, PCB_DRV_A6282_2021-11-23.pcbdoc_2022-01-21.pcbdoc, PickAndPlace_PCB_DRV_A6282_2021-11-23.pcbdoc_2022-01-24.csv]
2022-08-11 Igualación de hora con encoder
2022-09-07 Programa para igualar genérico
    Se pueden utilizar las dos versiones de hw que se disponen
2022-11-27 Reloj de 4 digitos
    Se implementa reloj de 4 digitos
2023-02-06 RelojAzul y pruebas Micropython
    [Digitos_5x8.xlsx]
2023-02-22 Se depura reloj matriz 16x16
    [Digitos_5x8.xlsx]
2023-02-22 Update main.py
    Se puede escoger el pinout del driver
2023-07-04 RELOJ GPS basado en dos A6282 con ESP32
    PCB fabricado en JLCPCB
2023-09-30 Se añaden funciones de MQTT al reloj
2023-10-08 Control de reloj con MQTT
    Se añade control de parámetros de brillo, tiempo de actualización de reloj y huso horario vía NTP
2023-10-12 Se añade pruebas para manejar DFPlayer
2024-03-03 Se utiliza nueva definición de SPI por software y HW
    Se obtienen mejores resultados por SPI de software
